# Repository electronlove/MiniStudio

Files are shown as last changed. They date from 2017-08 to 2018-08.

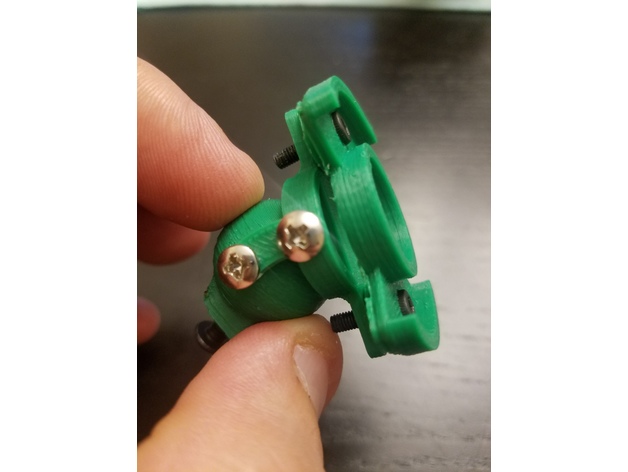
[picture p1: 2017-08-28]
Assembled-mount.jpg

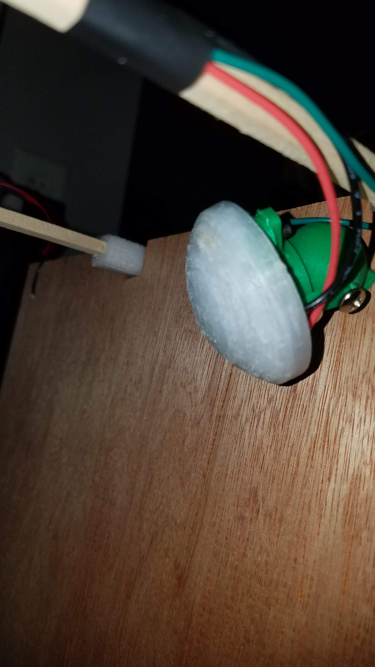
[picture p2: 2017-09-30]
diffuser with LED off.jpg

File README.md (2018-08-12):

# MiniStudio
**Construction of a miniature photo studio with web-controlled NeoPixels**

Miniature photo studio made of thin strip balsa wood, 3D-printed supports, paneling, and black fabric in place as a backdrop.  NeoPixel articulating mounts are installed in the front to provide RGBW lighting.

For web app to control the Neopixels, see https://github.com/uozuAho/pilights and **Instructions** in folder **web**

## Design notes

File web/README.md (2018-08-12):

For starters, first follow the installation instructions for https://github.com/uozuAho/pilights

Several files need to be modified

File name **flask-app.py**
  1. Add #!/usr/bin/env python
  2. Set the number of LEDS that you will be using.  The default is set to "NUM_LEDS = 8".  
  
  For the Adafruit NeoPixel ring, e.g. https://www.adafruit.com/product/2853, set NUM_LEDS = 12 for a single ring OR 24 for 2 rings in series

File name **neopixels.py**

  Under "class NeoPixels:":
  
  **CHANGE** 
  
def __init__(self, num_leds, output_pin=18, led_freq_hz=800000, dma=5,
                 invert=False, brightness=255):
        self.pixels = Adafruit_NeoPixel(num_leds, output_pin, led_freq_hz, dma,
            invert, brightness)
        self.pixels.begin()

  **TO**   
  
  def __init__(self, num_leds, output_pin=18, led_freq_hz=800000, dma=5,
                 invert=False, brightness=255, **channel=0, strip=ws.SK6812W_STRIP**):
        self.pixels = Adafruit_NeoPixel(num_leds, output_pin, led_freq_hz, dma,
            invert, brightness, **channel, strip**)
        self.pixels.begin()

  ALso change the relevant parts under **class NeoPixelsMock:** to include **channel** and **strip**

  **This is to specify the correct setting for Adafruit #2853 which uses the RGBW pixels**
  
  File name **index.html***
  Replace with new index.html in this directory
  
  **To make a system process**
  
  To autostart on boot:

1. Create a configuration file for neopixels.service:
- sudo nano /lib/systemd/system/neopixels.service

2. Enter the following information into the file:

[Unit]
- Description=NEOPIXEL WEB APP
- After=multi-user.target

[Service]
- Type=idle
- ExecStart=/usr/bin/env python /home/pi/pilights/flask-app.py **<--- Make sure the directory is correct.**

[Install]
- WantedBy=multi-user.target

3. Save and exit the editor.

4. Set permissions by:
- sudo chmod 644 /lib/systemd/system/neopixels.service

5. Configure the service
- sudo systemctl daemon-reload
- sudo systemctl enable neopixels.service

6. Reboot
- sudo reboot

7. Check the status of the running service
- sudo systemctl status neopixels.service

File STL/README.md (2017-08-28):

## NeoPixel Articulating Mount

Design and STL files to make mounts for AdaFruit 12 NeoPixel element rings 

	This assembly is designed to hold the 12 LED RGB(W) NeoPixel Ring (e.g. Product ID:2853; https://www.adafruit.com/product/2853). 
	The dimensions of the ring are: 3.68mm (O.D.) x 23.3mm (I.D.) x 325mm and the board fits in snuggly.

## Print Settings
	Printed supports are only required for the NeoPixel ring holder and should be oriented with the LED groove facing upward.
	The ball joint should be re-oriented with the flat face down.  An infill of 35% is adequate.  When printing in ABS, shrink should be taken into account (e.g. scaling to 104%)

## Preparing the Mounting Holes

	The components have mounting holes for 3mm screws and will need to be threaded with the appropriate sized tap. 
	The ball joint can accommodate a 30 mm screw with a nyloc nut instead of individual screws.
	There should be some play in the joint to allow for movement.

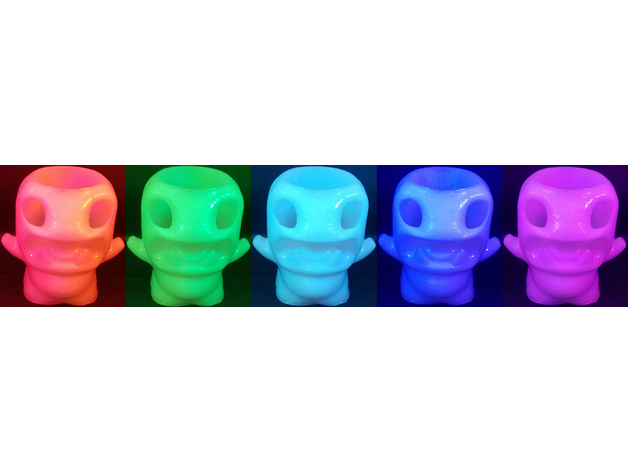
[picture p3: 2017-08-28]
MiniStudio-Lighting.jpg

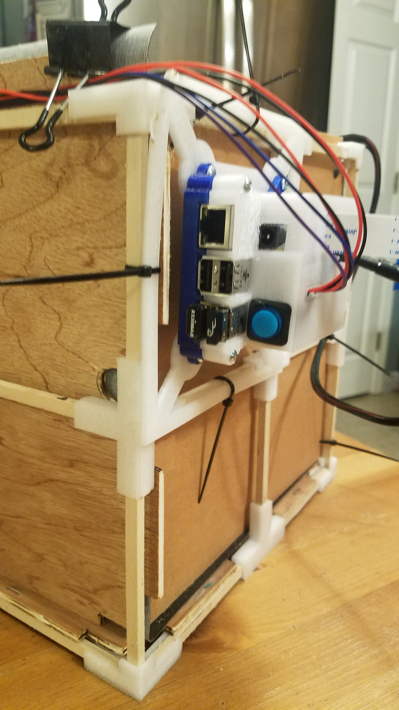
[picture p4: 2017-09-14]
MiniStudio with Pi.jpg

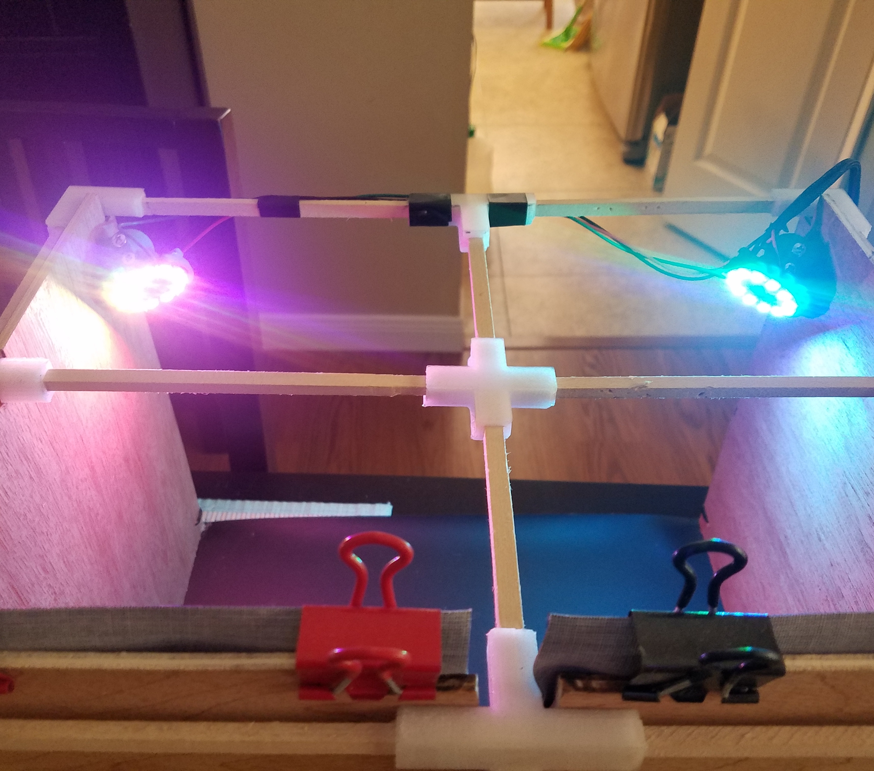
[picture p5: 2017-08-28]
Neopixel lighting.jpg

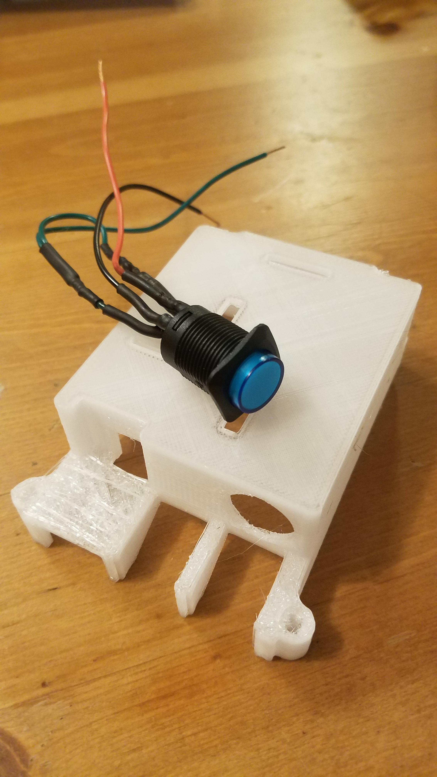
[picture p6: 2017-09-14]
Raspberry Pi case top.jpg

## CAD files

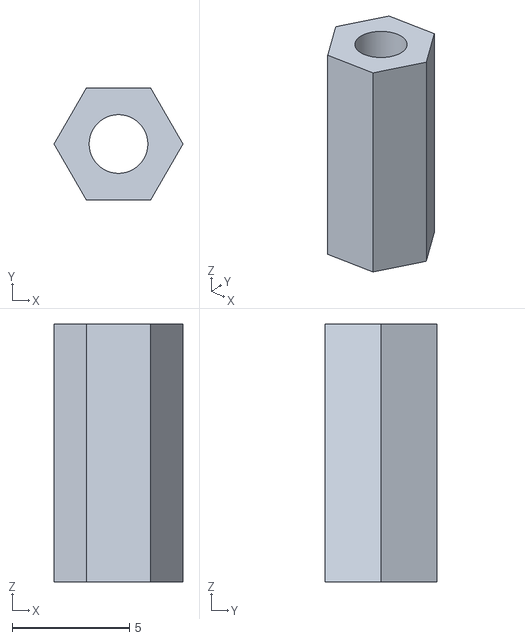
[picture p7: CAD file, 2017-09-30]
Standoffs_hex.stl
5.50 x 4.76 x 11.0

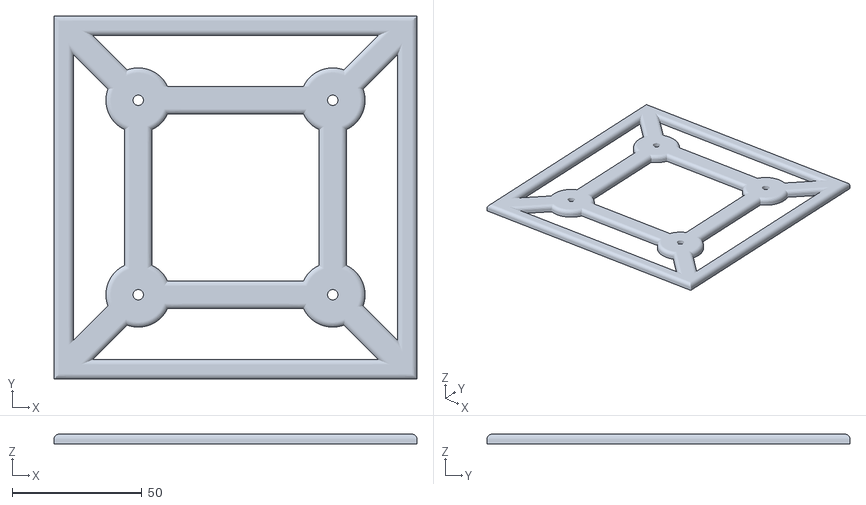
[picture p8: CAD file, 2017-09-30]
STL/VESA mount.stl
140.0 x 140.0 x 3.75

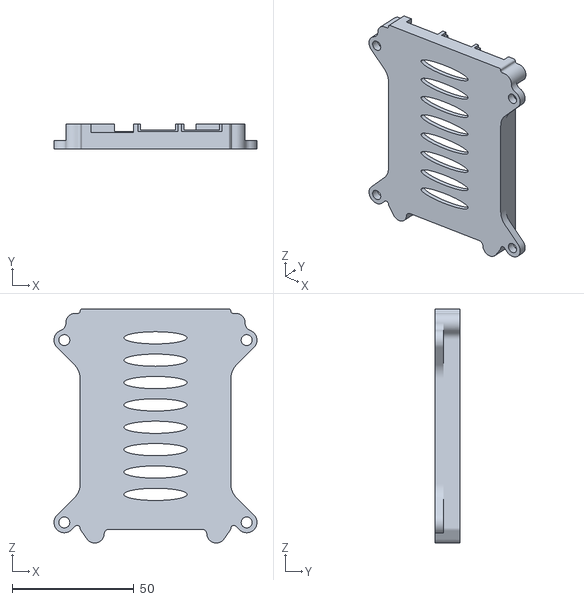
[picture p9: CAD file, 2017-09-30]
STL/RPI Case for HAT and switch bottom.stl
83.5 x 10.3 x 96.2

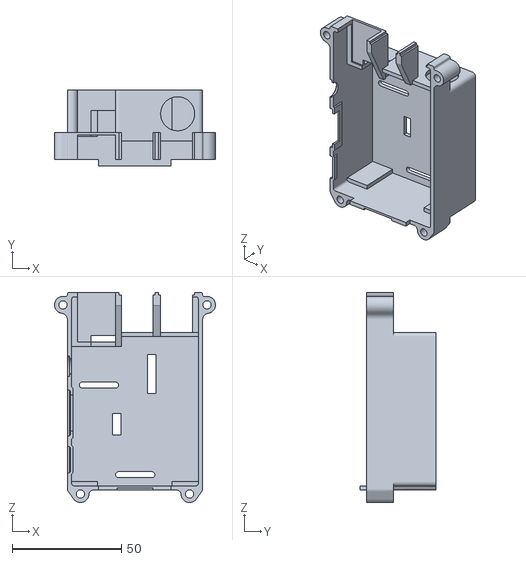
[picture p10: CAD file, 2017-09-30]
STL/RPI Case for HAT and switch.stl
73.8 x 35.0 x 96.3

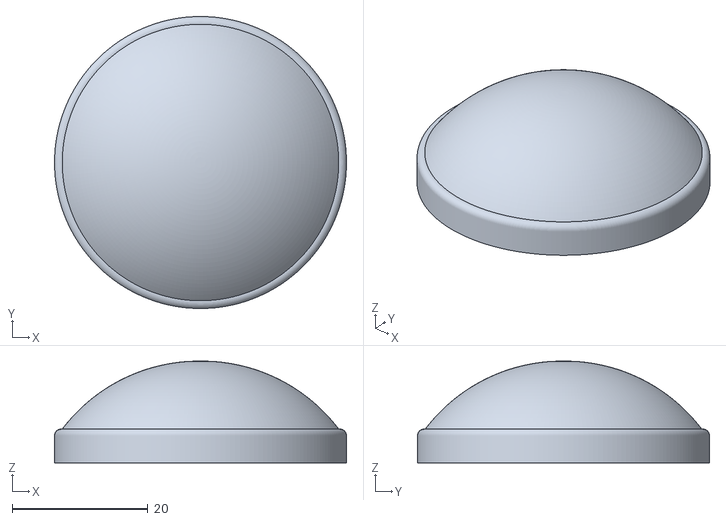
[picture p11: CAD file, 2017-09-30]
STL/Diffuser_mod.stl
43.0 x 43.0 x 15.0

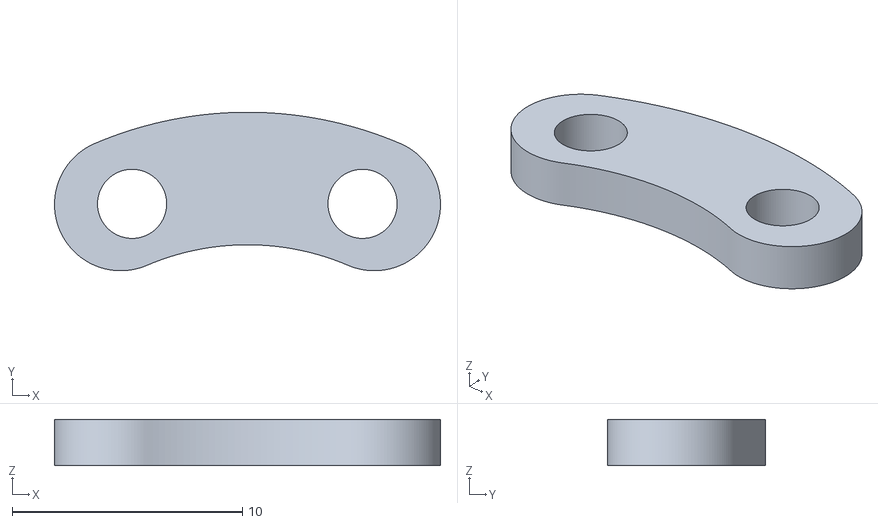
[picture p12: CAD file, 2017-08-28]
STL/curved_bracket.stl
16.7 x 6.87 x 2.00

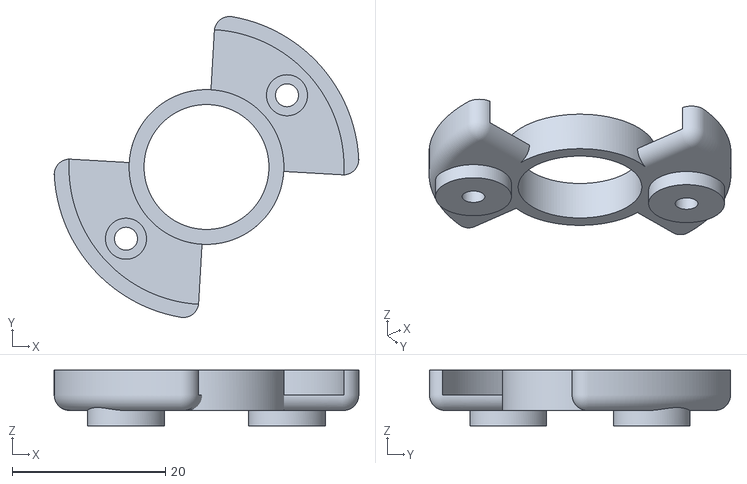
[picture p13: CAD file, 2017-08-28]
STL/LED_holder_merge.stl
39.7 x 39.3 x 7.25

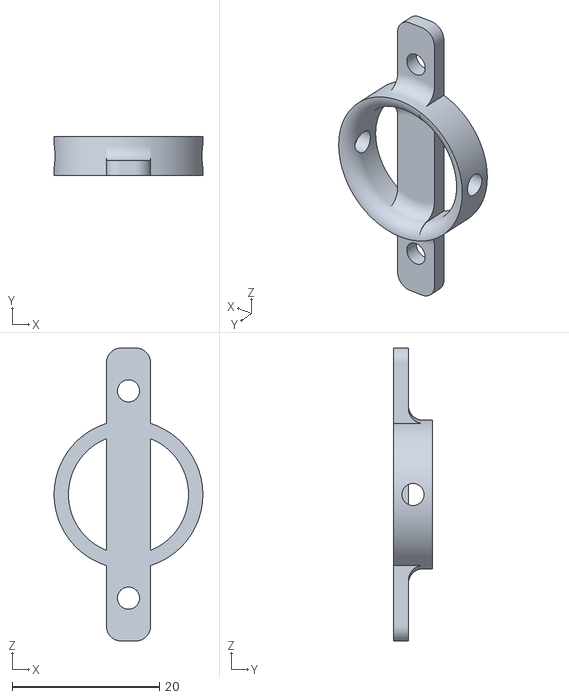
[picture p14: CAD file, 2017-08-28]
STL/LED_base_merged.stl
20.2 x 5.25 x 39.8

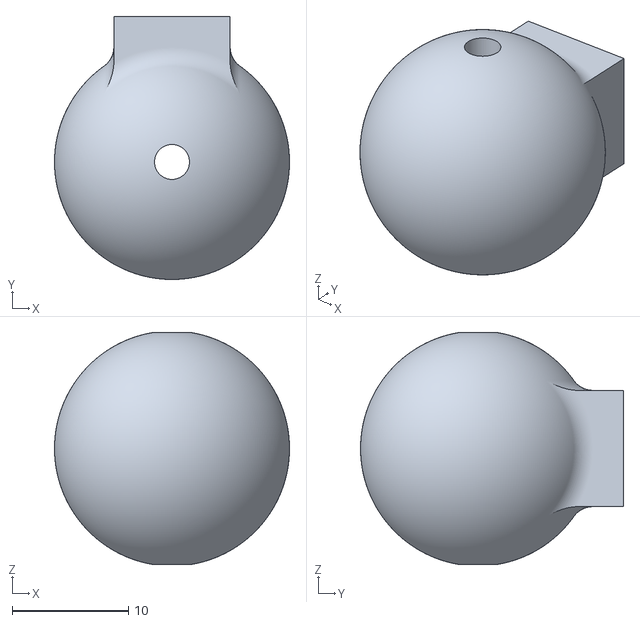
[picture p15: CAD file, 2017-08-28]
STL/Ball_joint_mount.stl
20.2 x 22.6 x 20.0

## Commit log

2017-08-28 Front of MiniStudio with NeoPixel mounts
2017-08-28 NeoPixel Lighting with 2 x 12 LEDa
2017-08-28 NeoPixel Ring Mount Rendering
2017-08-28 3D Rendering of Assembled NeoPixel Mount
2017-09-30 Add files via upload
    LED assembly with diffuser
2017-09-30 LED assembly with diffuser
2017-09-30 LED assembly with diffuser mounted to MiniStudio
2017-09-30 RPI Case for HAT and Latching Power Switch - Top
    [RPI Case for HAT and switch.stl]
2017-09-30 RPI Case - bottom
    [RPI Case for HAT and switch bottom.stl]
2017-09-30 VESA mount for RPI Case to MiniStudio
    [VESA mount.stl]
2017-09-30 11 mm standoffs for RPI HAT
    [Standoffs_hex.stl]
